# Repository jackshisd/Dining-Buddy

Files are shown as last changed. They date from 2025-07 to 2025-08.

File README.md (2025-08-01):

# Dining Buddy v6.3  
**ESP32-C3 OLED Keychain for UCLA Dining Menus + Weather Display**

## 🆕 Newest Features 6.0 -> 6.3

-  **Safe Wi-Fi Shutdown:** Device now safely enters deep sleep when unable to connect to Wi-Fi.
-  **Manual Wi-Fi Retry:** Long press the button to retry Wi-Fi connection without rebooting.
-  **Smarter Menu Downloads:** Optimized algorithm avoids redundant downloads, saving time and bandwidth.
-  **Bug Fixes & Stability:** Various minor improvements for a more reliable experience.
-  **Custom Enclosure:** 3D-printed and designed a protective case for portability.
-  **PCB Revision 2:** Updated layout for smoother button presses and improved assembly.

## Overview

Dining Buddy is an ultra-compact ESP32-C3-based keychain device that displays **UCLA dining hall menus** and **real-time weather**, with full offline functionality, minimal power use, and intuitive controls—all on a tiny OLED screen.

Menus are downloaded once daily and displayed with smooth auto-scrolling. The device also includes a **date selection mode**, **hall switching**, and a **live weather page**. It deep sleeps after 30 seconds of inactivity and wakes automatically every night at 2:30 AM to rotate cached menu files and download new ones.

All interaction is handled with a **single button**, and menu data is stored in **SPIFFS**. The PCB was custom-designed in **KiCad** for a minimal, keychain-friendly form factor.

## Photos

### Prototype  
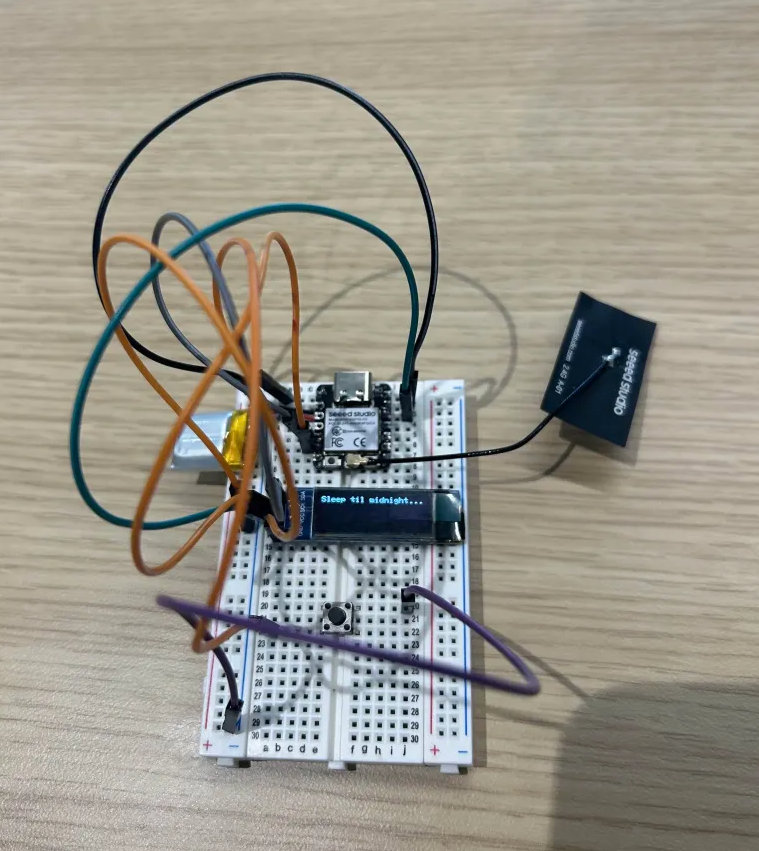
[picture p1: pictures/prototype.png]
Prototype


### Finished Keychain 
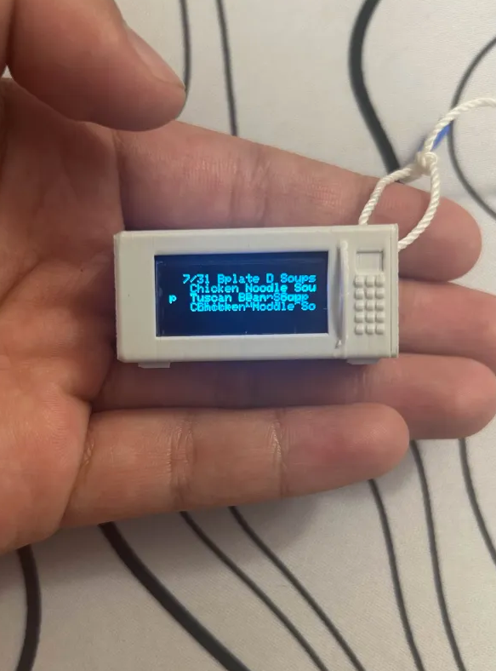
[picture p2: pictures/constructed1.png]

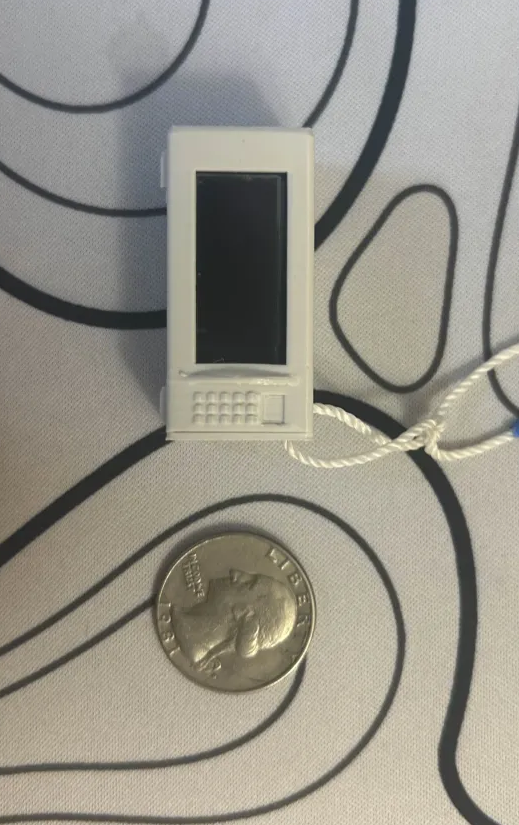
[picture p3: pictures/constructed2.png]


### Finished Solder Assembly  
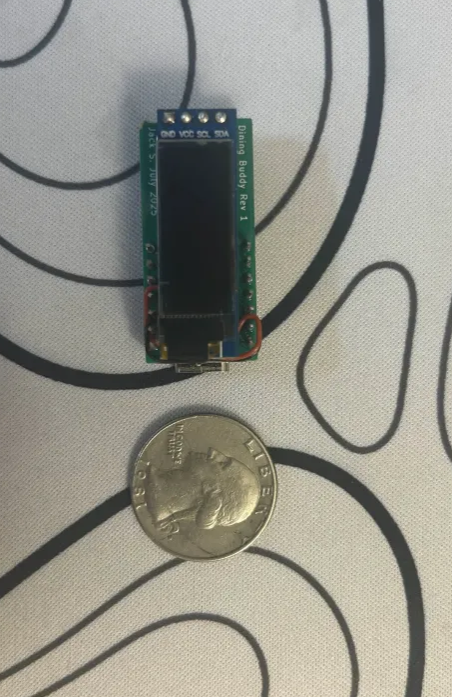
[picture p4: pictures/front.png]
Front

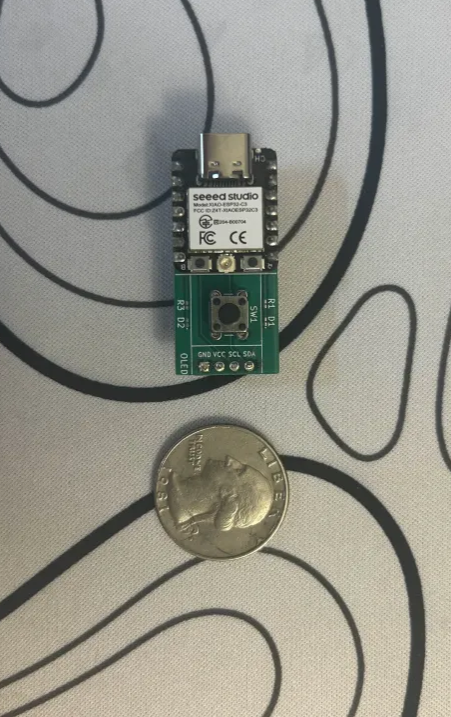
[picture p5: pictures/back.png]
Back

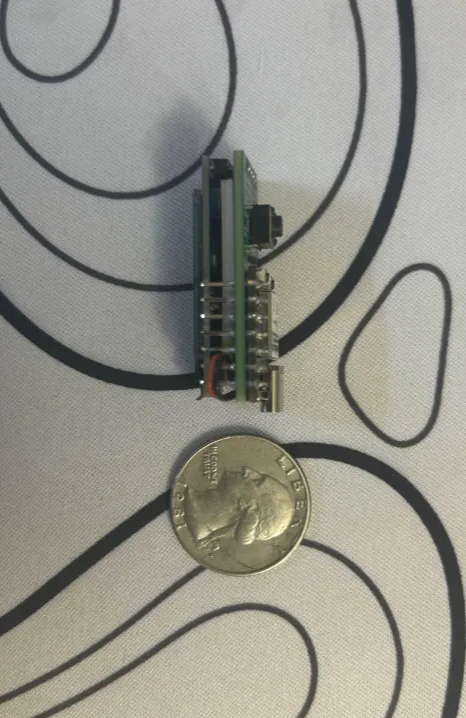
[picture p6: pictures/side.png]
Side


### Schematic  
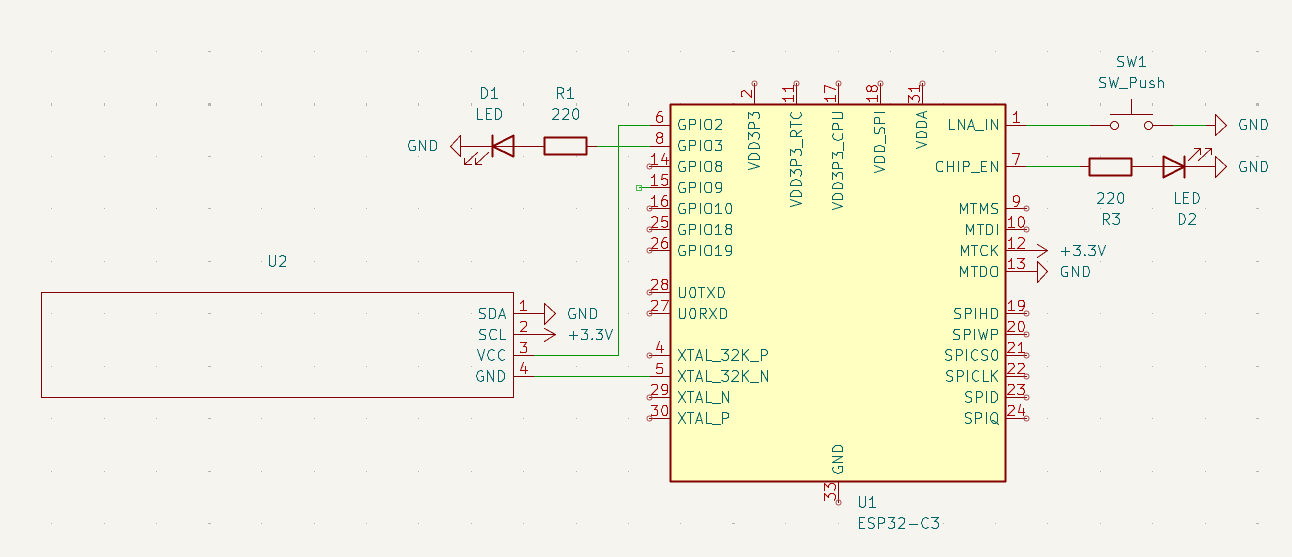
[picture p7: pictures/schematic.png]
Schematic


### PCB  
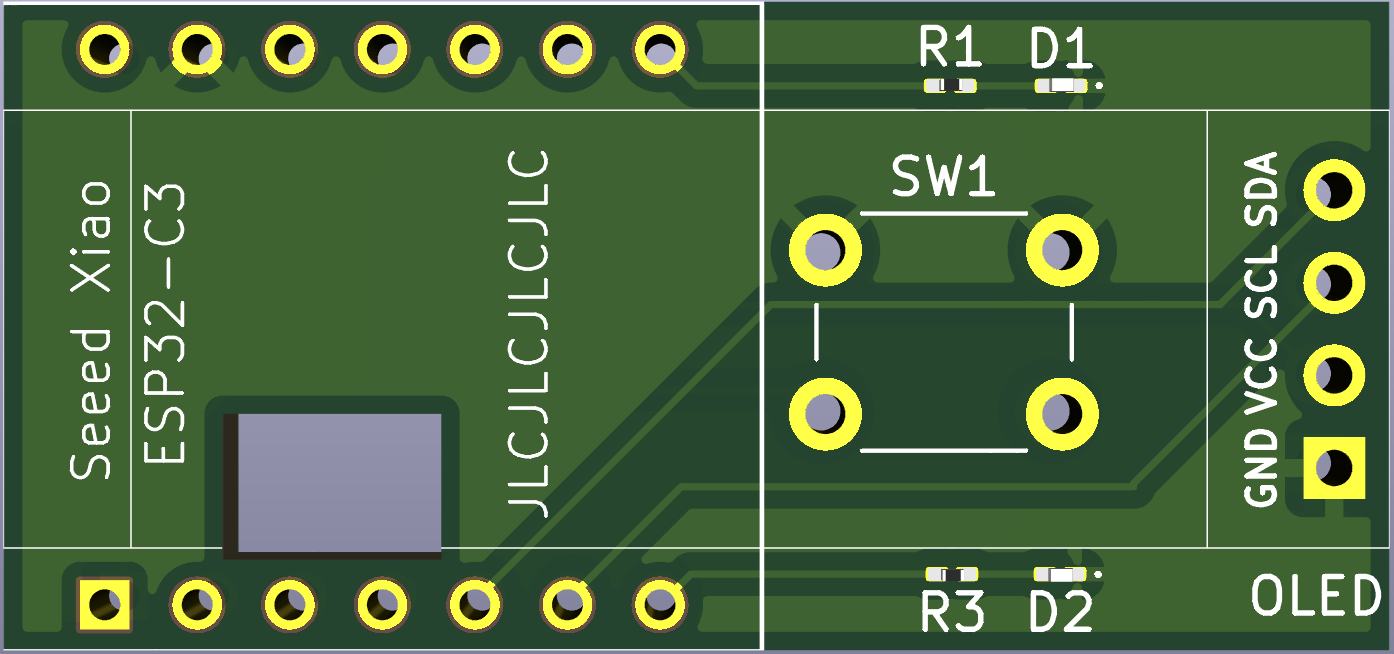
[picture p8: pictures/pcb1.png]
PCB Top

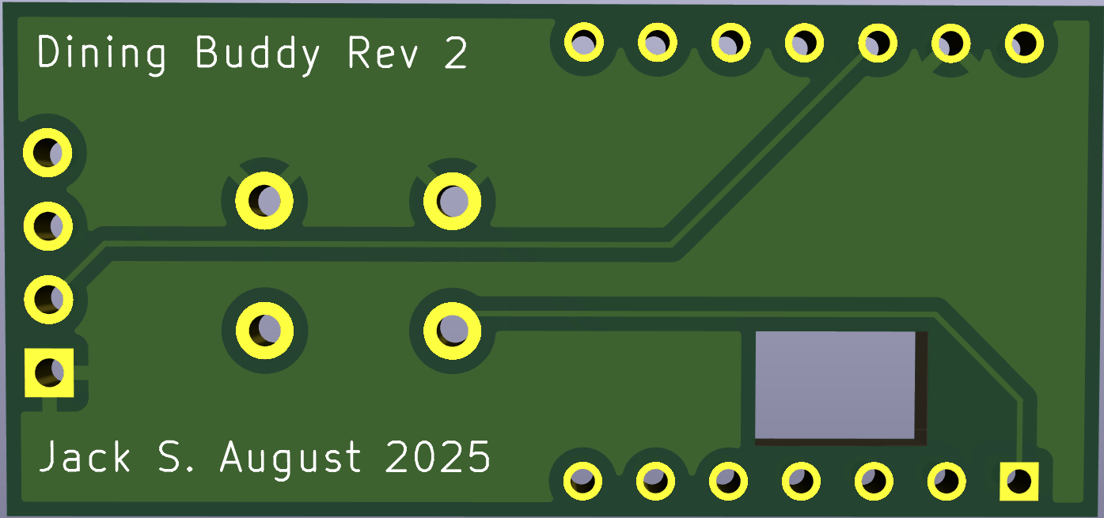
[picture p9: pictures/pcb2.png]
PCB Bottom


## Features

- 📅 View current and future dining menus (up to 6 days)
- 🏛️ Supports Bruin Plate, Epicuria, De Neve, and Rendezvous
- 🌦️ Weather fetch from [wttr.in](https://wttr.in)
- 🕒 Deep sleep with scheduled nightly wake (2:30 AM)
- 📡 Wi-Fi download over UCLA Wi-Fi or eduroam
- 🪛 Single-button interaction (short, long, double press)
- 🔋 OLED shuts off in deep sleep to preserve battery
- 🧾 All menus saved as clean, compact `.menu` files

## 🔧 Bill of Materials

| Component | Description |
|---|---|
| **ESP32-C3** | Seeed Studio ESP32-C3 dev board |
| **OLED Display** | 0.91" I2C SSD1306 (128×32) |
| **Push Button** | 6mm tactile push button |
| **Custom PCB** | Designed in KiCad for compact layout |
| **0603 Resistor** (optional)| 220Ω for LED indicator |
| **0603 LED** (optional) | Miscellaneous LED feedback |

## 🕹 User Guide

**Navigation is controlled by one button:**

| Press Type | Action |
|---|---|
| Short Press | Next menu section |
| Long Press | Switch to next dining hall |
| Double Press | Enter/exit date select mode |
| Long in Date Mode | Show weather |
| Short in Date Mode| Scroll day forward |
| Double in Date Mode| Confirm date + return to menu |
| Inactivity (30s)  | Enter deep sleep |

**Modes:**

- **Normal Mode:** Default menu viewing mode with auto-scroll
- **Date Select Mode:** Choose a day (up to 5 days ahead)
- **Weather Mode:** Shows date, time, and latest weather

## How Menus Are Managed

- On first boot, menus for the next 5 days are downloaded.
- Every night at 2:30 AM, yesterday’s menus are deleted, future menus are shifted forward, and the new sixth day is fetched.
- Menu data is extracted from HTML pages and saved as readable text.

## Setup Instructions

1. Flash the ESP32-C3 with the `DiningBuddy` sketch using Arduino IDE.
2. Add your local Wi-Fi or eduroam credentials to `LOCAL_SSID`, `LOCAL_PASS`, and `EAP_*` fields.
3. On boot, the device downloads menus and displays the current one.
4. Power off is automatic after inactivity; just press the button to wake.

## Hardware

- **MCU**: ESP32-C3 (Wi-Fi, deep sleep capable)
- **Display**: 128×32 OLED (SSD1306 via I2C)
- **Button**: Wired to GPIO 2 (input with pull-up)
- **LED**: Optional, wired to GPIO 21 via 220Ω resistor
- **Power**: LiPo or USB 5V
- **PCB**: Designed in KiCad for ultra-compact fit on a keychain

## Future Improvements

- Battery charging circuit on PCB  
- Auto time zone detection via Wi-Fi  
- Menu item filtering (vegetarian, vegan, etc.)  
- BLE companion app?

## 👤 Author

**Jack Shi**  
📧 jackmshi@ucla.edu  
🔬 UCLA Electrical Engineering

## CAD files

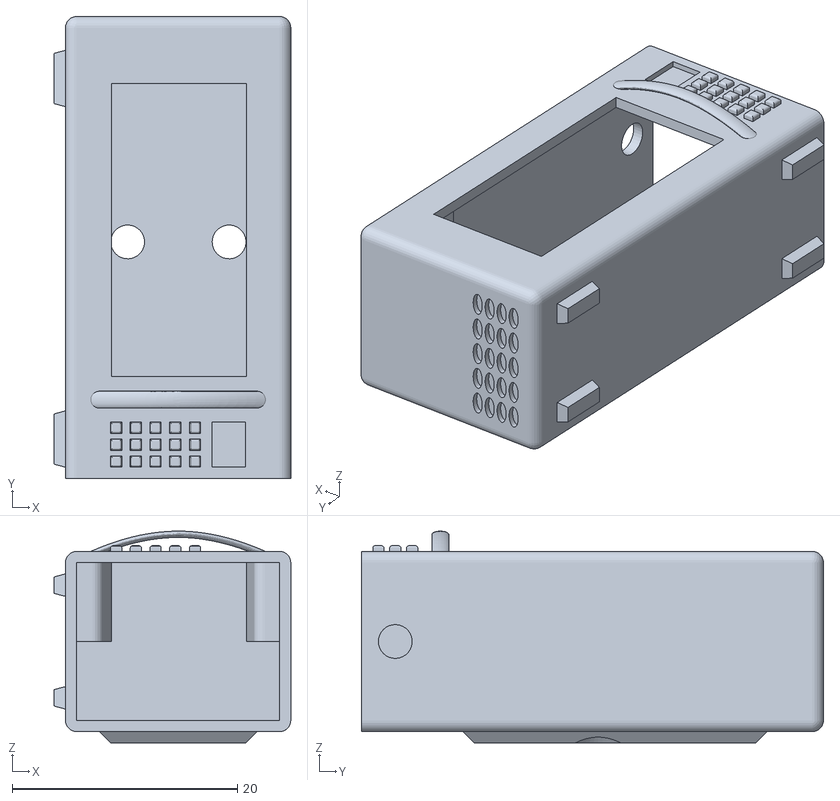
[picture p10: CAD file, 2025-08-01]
stl (3d print)/body.stl
21.0 x 41.0 x 18.8

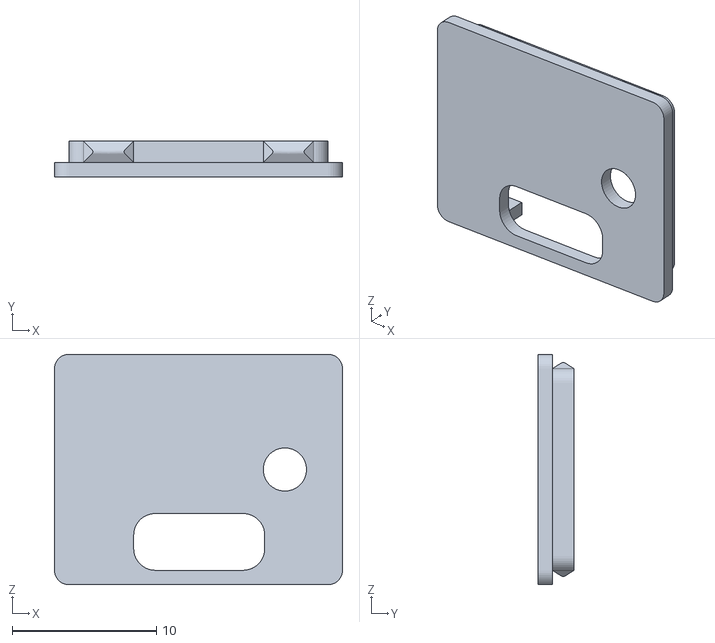
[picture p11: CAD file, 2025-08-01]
stl (3d print)/lid.stl
20.0 x 2.50 x 16.0

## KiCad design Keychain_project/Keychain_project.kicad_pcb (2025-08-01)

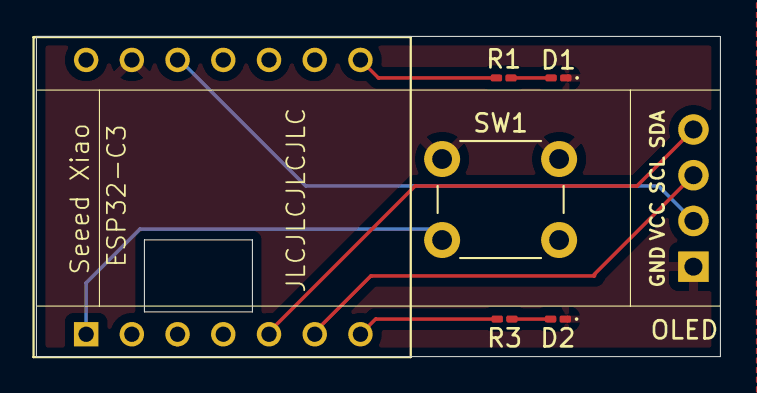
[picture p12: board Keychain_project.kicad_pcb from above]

Board: 2 copper layers, 38.0 x 17.8 mm, 7 parts (0 on the bottom side), 10 nets.

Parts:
D1, D2: LED; LED_0201_0603Metric_Pad0.64x0.40mm_HandSolder
R1, R3: 220; R_0201_0603Metric_Pad0.64x0.40mm_HandSolder
SW1: SW_Push; SW_PUSH_6mm
U1: ESP32-C3; MODULE_113991054
U2: SSD1306-0.91-OLED-4pin-128x32 (REVERSED)

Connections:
+3.3V: U1.12 (MTCK), U2.2 (SCL)
GND: D1.1 (K), D2.1 (K), SW1.1, U1.13 (MTDO), U2.1 (SDA)
unnamed: D1.2 (A), R1.2
unnamed: D2.2 (A), R3.1
unnamed: R3.2, U1.7 (CHIP_EN)
unnamed: U1.6 (GPIO2), U2.3 (VCC)
unnamed: R1.1, U1.8 (GPIO3)
unnamed: SW1.2, U1.1 (LNA_IN)
unnamed: U1.2 (VDD3P3), U1.3 (VDD3P3)
unnamed: U1.5 (XTAL_32K_N), U2.4 (GND)

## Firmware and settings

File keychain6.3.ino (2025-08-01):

#include <Wire.h>
#include <Adafruit_GFX.h>
#include <Adafruit_SSD1306.h>
#include <WiFi.h>
#include <WiFiClientSecure.h>
#include <SPIFFS.h>
#include <time.h>
#include <esp_sleep.h>
#include <esp_eap_client.h>

/* ---------- Wi-Fi ---------- */
#define EAP_ANON "anon@ucla.edu"
#define EAP_ID "your_email"
#define EAP_PASS "yeur_password"
const char *LOCAL_SSID = "Lena2";
const char *LOCAL_PASS  = "LenaLenaLena";

/* ---------- OLED ---------- */
#define SCREEN_WIDTH 128
#define SCREEN_HEIGHT 32
#define OLED_RESET    -1
Adafruit_SSD1306 display(SCREEN_WIDTH, SCREEN_HEIGHT, &Wire, OLED_RESET);

/* ---------- BUTTON ---------- */
const int BUTTON_PIN = 2;
const unsigned long DEBOUNCE_MS = 50;
const unsigned long LONGPRESS_MS = 600;
const unsigned long DOUBLECLICK_MS = 400;

/* ---------- LED ---------- */
const int LED_PIN = 21; // Choose your GPIO
RTC_DATA_ATTR bool wifiFailed = false;


/* ---------- State Vars ---------- */
bool lastButtonState = HIGH;
bool buttonState = HIGH;
unsigned long lastDebounceTime = 0;

unsigned long pressStartTime = 0;
bool longPressDetected = false;

unsigned long lastInteractionTime = 0;

int clickCount = 0;
unsigned long lastClickTime = 0;

/* ---------- Modes ---------- */
enum Mode {
  MODE_NORMAL,
  MODE_DATE_SELECT,
  MODE_WEATHER
};

Mode currentMode = MODE_NORMAL;

/* ---------- RTC Vars ---------- */
RTC_DATA_ATTR time_t lastMenuFetch = 0;

/* ---------- Dining Halls ---------- */
struct Hall {
  const char *name;
  const char *host;
  const char *pathBase;
  const char *fileToday;
} halls[] = {
  { "Bruin Plate", "dining.ucla.edu", "/bruin-plate/", "/bplate.menu" },
  { "Epicuria",    "dining.ucla.edu", "/epicuria-at-covel/", "/covel.menu" },
  { "De Neve",     "dining.ucla.edu", "/de-neve-dining/", "/deneve.menu" },
  { "Rendezvous",  "dining.ucla.edu", "/rendezvous/", "/rendezvous.menu" }
};

const int NUM_HALLS = sizeof(halls) / sizeof(halls[0]);
int currentHallIndex = 0;

/* ---------- Menu Pages ---------- */
struct MenuPage {
  String mealLetter;
  String title;
  String scrollingText;
};

std::vector<MenuPage> pages;
int currentPageIndex = 0;

/* ---------- Scrolling ---------- */
int scrollOffset = 0;
unsigned long lastScroll = 0;
const int SCROLL_SPEED_MS = 100;

String headerScrollText = "";
int headerScrollOffset = 0;
unsigned long headerLastScroll = 0;
const int HEADER_SCROLL_SPEED_MS = 150;

/* ---------- Weather/Date ---------- */
String currentWeather = "";
String currentDate = "";
String currentTimeStr = "";
unsigned long lastWeatherRefresh = 0;
const unsigned long WEATHER_REFRESH_MS = 10 * 60 * 1000UL;

/* ---------- Date Select Vars ---------- */
String selectedDate = "";
int selectedDayIndex = 0;
int dateSelectScroll = 0;

/* ---------- Prototypes ---------- */
void connectEduroam();
void connectLocalWiFi(const char *ssid, const char *pwd);
bool downloadPage(const char*, const char*);
void extractMenu(const char*);
void loadMenuPagesForCurrentHall();
void showCurrentPage();
void scrollText();
void handleButton();
void handleClick();
void shortPressAction();
void longPressAction();
void doublePressAction();
void showWeatherPage();
void fetchWeather();
void fetchDateTime();
void scheduleDeepSleepUntilNightWake();
void rotateAndFetchMenus();
String cleanText(String);
void showProgress(const String&);
String getCurrentMealLetter();
void setPageForCurrentMeal();
bool shouldFetchMenusToday();
void fetchMenusForNextNDays(int);
void cleanOldMenus();
String makeMenuFilename(const Hall &, const String &);
String getDateString(int);
String getCompactDate(int);
String getDayOfWeek(int);
void showDateSelectScreen();
void fixInvalidDateFiles();

/* ---------- Setup ---------- */

void setup() {
  Serial.begin(115200);
  delay(300);

  Wire.begin(6, 7);
  pinMode(BUTTON_PIN, INPUT_PULLUP);
  pinMode(LED_PIN, OUTPUT);

  if (!display.begin(SSD1306_SWITCHCAPVCC, 0x3C)) {
    Serial.println("SSD1306 failed");
    while (1);
  }
display.clearDisplay();
display.setTextSize(1);
display.setTextColor(SSD1306_WHITE);
display.setCursor(0, 0);
display.println("Dining Buddy v6.3");
display.println("I'm waking up...");
display.display();

  if (!SPIFFS.begin(true)) {
    showProgress("Sorry! :( SPIFFS failed!");
    while (1);
  }

  if(wifiFailed){
    digitalWrite(LED_PIN, HIGH);
    
    // Show multi-line message
    display.clearDisplay();
    display.setCursor(0, 0);
    display.setTextSize(1);
    display.setTextColor(SSD1306_WHITE);
    showProgress("WiFi failed! Sorry :( Hold button 3s to reboot me!");
    
    
    // Long press to restart
    unsigned long pressStartTime = 0;
    bool longPressDetected = false;
    
    while (1) {
      bool buttonPressed = digitalRead(BUTTON_PIN) == LOW;
      
      if (buttonPressed && !longPressDetected) {
        if (pressStartTime == 0) {
          pressStartTime = millis();
        } else if (millis() - pressStartTime > 3000) { // 3 second long press
          longPressDetected = true;
          showProgress("Restarting...");
          delay(1000);
          ESP.restart(); // Restart the device
        }
      } else if (!buttonPressed) {
        pressStartTime = 0;
      }
      
      delay(100); // Check every 100ms
    }
  }

  configTzTime("PST8PDT,M3.2.0,M11.1.0", "pool.ntp.org", "time.nist.gov");
  delay(800);

  esp_sleep_wakeup_cause_t reason = esp_sleep_get_wakeup_cause();
  switch (reason) {
    case ESP_SLEEP_WAKEUP_TIMER:
      Serial.println("Wakeup by TIMER");
      if (!connectLocalWiFi(LOCAL_SSID, LOCAL_PASS, 30000)) {
        scheduleDeepSleepUntilNightWake();
        return;
      }
      rotateAndFetchMenus();
      lastMenuFetch = time(NULL);
      WiFi.disconnect(true);
      break;

    case ESP_SLEEP_WAKEUP_GPIO:
      Serial.println("Wakeup by GPIO");
      break;

    default:
      Serial.printf("Cold boot: %d\n", reason);
      if (!connectLocalWiFi(LOCAL_SSID, LOCAL_PASS, 30000)) {
        scheduleDeepSleepUntilNightWake();
        return;
      }
      fetchMenusForNextNDays(5);
      lastMenuFetch = time(NULL);
      WiFi.disconnect(true);
      break;
  }

  cleanOldMenus();

  selectedDate = getDateString(0);
  loadMenuPagesForCurrentHall();
  setPageForCurrentMeal();
  showCurrentPage();
  lastInteractionTime = millis();
}

/* ---------- Loop ---------- */

void loop() {
  handleButton();

  if (currentMode == MODE_WEATHER) {
    if (millis() - lastWeatherRefresh > WEATHER_REFRESH_MS) {
      if (!connectLocalWiFi(LOCAL_SSID, LOCAL_PASS, 30000)) {
        scheduleDeepSleepUntilNightWake();
        return;
      }
      fetchDateTime();
      fetchWeather();
      lastWeatherRefresh = millis();
    }
    showWeatherPage();
  } else if (currentMode == MODE_DATE_SELECT) {
    // nothing
  } else {
    scrollText();
  }

  if (currentMode == MODE_NORMAL && millis() - lastInteractionTime > 30000) {
    scheduleDeepSleepUntilNightWake();
  }
}

/* ---------- Midnight Logic ---------- */

void scheduleDeepSleepUntilNightWake() {
  struct tm timeinfo;
  if (!getLocalTime(&timeinfo)) {
    wifiFailed = true;
    Serial.println("No time info. Skipping sleep.");
    // Turn off display to save power
    display.ssd1306_command(SSD1306_DISPLAYOFF);

    esp_deep_sleep_enable_gpio_wakeup(
        1ULL << GPIO_NUM_2,
        ESP_GPIO_WAKEUP_GPIO_LOW
    );

    esp_deep_sleep_start();
    return; // CRITICAL: Add return statement
  }

  timeinfo.tm_hour = 2;
  timeinfo.tm_min  = 30;
  timeinfo.tm_sec  = 0;

  time_t targetWake = mktime(&timeinfo);
  if (targetWake <= time(NULL)) {
    targetWake += 86400;
  }

  time_t secondsUntilWake = targetWake - time(NULL);

  if (secondsUntilWake < 30) {
    secondsUntilWake = 86400;
  }

  Serial.printf("Sleeping %ld seconds until 2:30 AM\n", secondsUntilWake);

  // Turn off display to save power
  display.ssd1306_command(SSD1306_DISPLAYOFF);

  esp_sleep_enable_timer_wakeup(secondsUntilWake * 1000000ULL);

  esp_deep_sleep_enable_gpio_wakeup(
      1ULL << GPIO_NUM_2,
      ESP_GPIO_WAKEUP_GPIO_LOW
  );

  esp_deep_sleep_start();
}




void rotateAndFetchMenus() {

  showProgress("Rotate + fetch...");

  String today = getDateString(0);   // 2025-07-10
  String day6  = getDateString(5);   // 2025-07-15

  for (int h = 0; h < NUM_HALLS; h++) {

    String todayFile       = halls[h].fileToday;          // /bplate.menu
    String todayFutureFile = makeMenuFilename(halls[h], today); // /bplate_2025-07-10.menu
    bool   haveToday       = false;

    // If we *do* have the dated copy, rotate it in
    if (SPIFFS.exists(todayFutureFile)) {

      if (SPIFFS.exists(todayFile)) SPIFFS.remove(todayFile);
      if (SPIFFS.rename(todayFutureFile, todayFile)) {
        haveToday = true;
        showProgress("Rotated " + todayFutureFile);
      }
    }

    // If rotation failed, download today explicitly
    if (!haveToday) {
      String path = String(halls[h].pathBase) + "?date=" + today;
      showProgress(String("DL today ") + halls[h].name);
      if (downloadPage(halls[h].host, path.c_str())) {
        extractMenu(todayFile.c_str());
      }
    }
  }

  // --- grab the new 6th-day menu ---
  for (int h = 0; h < NUM_HALLS; h++) {
    String path = String(halls[h].pathBase) + "?date=" + day6;
    String file = makeMenuFilename(halls[h], day6);
    
    // Check if 6th-day file exists and has content
    if (SPIFFS.exists(file)) {
      File checkFile = SPIFFS.open(file, FILE_READ);
      if (checkFile && checkFile.size() > 100) { // File exists and has meaningful content
        showProgress(String("Skip +6 ") + halls[h].name);
        checkFile.close();
        continue; // Skip downloading this file
      }
      checkFile.close();
    }
    
    showProgress(String("DL +6 ") + halls[h].name);
    if (downloadPage(halls[h].host, path.c_str())) extractMenu(file.c_str());
  }

  showProgress("✅ rotation done");
}



/* ---------- Existing Functions ---------- */

String makeMenuFilename(const Hall &h, const String &dateStr) {
  String base = h.name;
  base.toLowerCase();
  base.replace(" ", "");
  return "/" + base + "_" + dateStr + ".menu";
}

String getDateString(int offsetDays) {
  time_t t = time(NULL) + offsetDays * 86400;
  struct tm tm;
  localtime_r(&t, &tm);
  char buf[11];
  strftime(buf, sizeof(buf), "%Y-%m-%d", &tm);
  return String(buf);
}

String getCompactDate(int offset) {
  time_t now = time(NULL);
  now += offset * 86400;
  struct tm *tm = localtime(&now);
  return String(tm->tm_mon + 1) + "/" + String(tm->tm_mday);
}

String getDayOfWeek(int offset) {
  time_t now = time(NULL);
  now += offset * 86400;
  struct tm *tm = localtime(&now);
  char buf[10];
  strftime(buf, sizeof(buf), "%a", tm);
  return String(buf);
}

void cleanOldMenus() {
  String today = getDateString(0);
  File root = SPIFFS.open("/");
  while (File file = root.openNextFile()) {
    String name = file.name();
    if (name.endsWith(".menu")) {
      int u = name.lastIndexOf('_');
      int d = name.lastIndexOf('.');
      if (u != -1 && d != -1 && d > u) {
        String datePart = name.substring(u + 1, d);
        if (datePart < today) {
          SPIFFS.remove(name);
          showProgress("Deleted " + name);
        }
      }
    }
  }
}

bool shouldFetchMenusToday() {
  fetchDateTime();
  struct tm nowTime;
  if (!getLocalTime(&nowTime)) return true;
  if (lastMenuFetch == 0) return true;
  struct tm *last = localtime(&lastMenuFetch);
  return nowTime.tm_yday != last->tm_yday;
}

void fetchMenusForNextNDays(int numDays) {
  for (int i = 0; i <= numDays; i++) {
    String dateStr = getDateString(i);
    for (Hall &h : halls) {
      String path;
      String fileName;
      if (i == 0) {
        path = h.pathBase;
        fileName = h.fileToday;
      } else {
        path = String(h.pathBase) + "?date=" + dateStr;
        fileName = makeMenuFilename(h, dateStr);
      }
      
      // Check if file exists and has content
      if (SPIFFS.exists(fileName)) {
        File checkFile = SPIFFS.open(fileName, FILE_READ);
        if (checkFile && checkFile.size() > 100) { // File exists and has meaningful content
          showProgress("Skip " + String(h.name) + " " + dateStr);
          checkFile.close();
          continue; // Skip downloading this file
        }
        checkFile.close();
      }
      
      showProgress("DL " + String(h.name) + " " + dateStr);
      if (downloadPage(h.host, path.c_str())) {
        extractMenu(fileName.c_str());
      } else {
        showProgress("DL fail: " + String(h.name) + " " + dateStr);
      }
    }
  }
  showProgress("✅ Done fetching menus.");
}

bool connectLocalWiFi(const char *ssid, const char *pwd, unsigned long timeoutMs) {
  showProgress("I'm Connecting to Wi-Fi...");
  WiFi.mode(WIFI_STA);
  WiFi.begin(ssid, pwd);
  unsigned long startAttempt = millis();
  while (WiFi.status() != WL_CONNECTED) {
    delay(350);
    if (millis() - startAttempt > timeoutMs) {
      showProgress("I searched for 30s but couldn't connect to Wi-Fi!");
      return false;
    }
  }
  showProgress("IP: " + WiFi.localIP().toString());
  return true;
}

void connectLocalWiFi(const char *ssid, const char *pwd) { // legacy wrapper for old calls
  connectLocalWiFi(ssid, pwd, 30000);
}

bool connectEduroam(unsigned long timeoutMs) {
  showProgress("I'm Connecting eduroam...");
  WiFi.mode(WIFI_STA);
  WiFi.begin("eduroam", WPA2_AUTH_PEAP,
             EAP_ANON, EAP_ID, EAP_PASS);
  unsigned long startAttempt = millis();
  while (WiFi.status() != WL_CONNECTED) {
    delay(350);
    if (millis() - startAttempt > timeoutMs) {
      showProgress("Wi-Fi timeout");
      return false;
    }
  }
  showProgress("IP: " + WiFi.localIP().toString());
  return true;
}

void connectEduroam() { // legacy wrapper for old calls
  connectEduroam(30000);
}

void showProgress(const String& msg) {
  Serial.println(msg);
  display.clearDisplay();
  display.setCursor(0, 0);
  display.setTextSize(1);
  display.setTextColor(SSD1306_WHITE);
  display.println("Dining Buddy v6.3");
  display.println(cleanText(msg));
  display.display();
}

void extractMenu(const char *dstFile) {
  File in = SPIFFS.open("/dump.html", FILE_READ);
  if (!in) {
    showProgress("/dump.html missing!");
    return;
  }

  File out = SPIFFS.open(dstFile, FILE_WRITE);
  if (!out) {
    showProgress("Can't create compact file.");
    in.close();
    return;
  }

  const char *SKIP_PHRASES[] = {
    "icon legend", "location &",
    "farm to table", "fresh, local, sustainable meals",
    "today’s dining hours", "today's dining hours", "address"
  };
  constexpr size_t N_SKIP = sizeof(SKIP_PHRASES) / sizeof(SKIP_PHRASES[0]);

  String content = "";
  String last = "";
  char level = 0;
  bool inTag = false;
  bool captureText = false;
  bool anything = false;
  String tag = "";

  auto unwanted = [&](const String &txt) {
    String low = txt; low.toLowerCase();
    for (size_t i = 0; i < N_SKIP; ++i)
      if (low.startsWith(SKIP_PHRASES[i])) return true;
    return false;
  };

  while (in.available()) {
    char c = in.read();
    if (!inTag && c == '<') {
      tag = "<";
      inTag = true;
      continue;
    }
    if (inTag) {
      tag += c;
      if (c == '>') {
        inTag = false;
        if (tag.startsWith("<h2") || tag.startsWith("<h3")) {
          level = tag.charAt(2);
          content = "";
          captureText = true;
        } else if (captureText &&
                  ((level == '2' && tag.startsWith("</h2")) ||
                   (level == '3' && tag.startsWith("</h3")))) {
          String trimmed = content; trimmed.trim();
          if (trimmed.length() && !unwanted(trimmed)) {
            if (!trimmed.equalsIgnoreCase(last)) {
              if (level == '2') {
                out.printf("\n=== %s ===\n", trimmed.c_str());
              } else {
                out.printf("- %s\n", trimmed.c_str());
              }
              last = trimmed;
              anything = true;
            }
          }
          captureText = false;
        }
        tag = "";
      }
      continue;
    }
    if (captureText) {
      if (c == '\n' || c == '\r') c = ' ';
      content += c;
    }
  }
  in.close(); out.close();

  if (anything) {
    showProgress("✅ Menu saved: " + String(dstFile));
  } else {
    showProgress("️ No headings found!");
  }
}

String cleanText(String s) {
  String out = "";
  for (size_t i = 0; i < s.length(); i++) {
    char c = s.charAt(i);
    if (c >= 32 && c <= 126) {
      out += c;
    }
  }
  return out;
}

void fetchDateTime() {
  struct tm timeinfo;
  if (!getLocalTime(&timeinfo)) {
    currentDate = "No RTC";
    currentTimeStr = "--:--";
    return;
  }
  char dateStr[20];
  char timeStr[10];
  strftime(dateStr, sizeof(dateStr), "%Y-%m-%d", &timeinfo);
  strftime(timeStr, sizeof(timeStr), "%H:%M", &timeinfo);
  currentDate = String(dateStr);
  currentTimeStr = String(timeStr);
}

void fetchWeather() {
  if (WiFi.status() != WL_CONNECTED) {
    currentWeather = "Wi-Fi lost";
    return;
  }
  WiFiClientSecure client;
  client.setInsecure();

  if (!client.connect("wttr.in", 443)) {
    currentWeather = "Weather fail";
    return;
  }

  client.print(
    "GET /?format=3 HTTP/1.1\r\n"
    "Host: wttr.in\r\n"
    "User-Agent: ESP32\r\n"
    "Connection: close\r\n\r\n"
  );

  bool headersEnded = false;
  while (client.connected()) {
    String line = client.readStringUntil('\n');
    line.trim();
    if (line.length() == 0) {
      headersEnded = true;
      break;
    }
  }

  if (!headersEnded) {
    currentWeather = "No weather";
    return;
  }

  if (client.available()) {
    String weatherLine = client.readStringUntil('\n');
    weatherLine.trim();
    weatherLine.replace(" :", ":");
    while (weatherLine.indexOf("  ") != -1) {
      weatherLine.replace("  ", " ");
    }
    currentWeather = cleanText(weatherLine);
    return;
  }
  currentWeather = "No weather";
}

bool downloadPage(const char *host, const char *path) {
  WiFiClientSecure cli;
  cli.setInsecure();

  showProgress("I'm downloading https://" + String(host) + String(path));
  if (!cli.connect(host, 443, 10000)) {
    showProgress("TLS failed");
    return false;
  }

  cli.printf(
    "GET %s HTTP/1.1\r\n"
    "Host: %s\r\n"
    "User-Agent: ESP32-MenuScraper\r\n"
    "Connection: close\r\n\r\n", path, host);

  String status = cli.readStringUntil('\n');
  int code = status.substring(9, 12).toInt();
  String loc;
  while (cli.connected()) {
    String h = cli.readStringUntil('\n');
    h.trim();
    if (h.length() == 0) break;
    if (h.startsWith("Location:")) loc = h.substring(9);
  }
  if ((code == 301 || 302) && loc.length()) {
    cli.stop();
    loc.trim();
    if (loc.startsWith("http")) {
      int s = loc.indexOf('/', loc.indexOf("://") + 3);
      String nHost = loc.substring(loc.indexOf("://") + 3, s);
      String nPath = loc.substring(s);
      return downloadPage(nHost.c_str(), nPath.c_str());
    }
    return downloadPage(host, loc.c_str());
  }

  File out = SPIFFS.open("/dump.html", FILE_WRITE);
  if (!out) {
    showProgress("Can't create dump.html");
    cli.stop();
    return false;
  }

  while (cli.connected() || cli.available()) {
    while (cli.available()) {
      out.write(cli.read());
    }
  }
  out.close();
  cli.stop();
  showProgress("✅ Downloaded.");
  return true;
}

void loadMenuPagesForCurrentHall() {
  pages.clear();

  String fileName;
  if (selectedDayIndex == 0) {
    fileName = halls[currentHallIndex].fileToday;
  } else {
    fileName = makeMenuFilename(halls[currentHallIndex], selectedDate);
  }

  File f = SPIFFS.open(fileName, FILE_READ);
  if (!f) {
    pages.push_back({"", "Error", "Menu missing."});
    return;
  }

  String pendingTitle = "";
  String pendingDishes = "";
  String currentMealLetter = "B";
  String lastMealLetter = "B";

  while (f.available()) {
    String line = f.readStringUntil('\n');
    line.trim();

    if (line.startsWith("===")) {
      String heading = line;
      heading.replace("=", "");
      heading.trim();

      bool isMeal = false;
      if (heading.equalsIgnoreCase("BREAKFAST")) {
        currentMealLetter = "B";
        isMeal = true;
      } else if (heading.equalsIgnoreCase("LUNCH")) {
        currentMealLetter = "L";
        isMeal = true;
      } else if (heading.equalsIgnoreCase("DINNER")) {
        currentMealLetter = "D";
        isMeal = true;
      }

      if (isMeal) {
        if (!pendingTitle.isEmpty() && !pendingDishes.isEmpty()) {
          pages.push_back({lastMealLetter, pendingTitle, pendingDishes});
        }
        pendingTitle = "";
        pendingDishes = "";
        lastMealLetter = currentMealLetter;
      } else {
        if (!pendingTitle.isEmpty() && !pendingDishes.isEmpty()) {
          pages.push_back({lastMealLetter, pendingTitle, pendingDishes});
        }
        pendingTitle = heading;
        pendingDishes = "";
      }
    } else if (line.startsWith("-")) {
      String dish = line.substring(1);
      dish.trim();
      pendingDishes += dish + " • ";
    }
  }
  f.close();

// ✅ NEW CHECK:
if (pages.empty()) {
  pages.push_back({"", "Notice!", "No menu found! Check back later!"});
}
}

void setPageForCurrentMeal() {
  String mealLetter = getCurrentMealLetter();
  for (size_t i = 0; i < pages.size(); i++) {
    if (pages[i].mealLetter == mealLetter) {
      currentPageIndex = i;
      return;
    }
  }
  currentPageIndex = 0;
}

void showCurrentPage() {
  String hallName = String(halls[currentHallIndex].name);
  hallName.replace("Bruin Plate", "Bplate");
  hallName.replace("Epicuria", "Epic");
  hallName.replace("Rendezvous", "Rende");

  MenuPage &page = pages[currentPageIndex];
  String dateStr = getCompactDate(selectedDayIndex);
  String header = dateStr + " " + hallName;
  
  // Only add meal letter if not Rendezvous
  if (page.mealLetter.length() > 0 && String(halls[currentHallIndex].name) != "Rendezvous") {
    header += " " + page.mealLetter;
  }
  
  header += " " + page.title;

  headerScrollText = cleanText(header) + "   ";
}
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

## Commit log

2025-07-22 added code, gerbers, and photos
2025-07-22 added files of assembly
2025-07-25 Upload Kicad Files
    [Keychain_project.kicad_pcb, Keychain_project.kicad_sch]
2025-08-01 Fixed photos and deleted unnecessary files
    [Keychain_project.kicad_pcb, Keychain_project.kicad_sch]
2025-08-01 added 3d print files
    [body.stl, lid.stl]
